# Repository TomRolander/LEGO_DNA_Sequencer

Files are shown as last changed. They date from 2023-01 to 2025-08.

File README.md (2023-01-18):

# LEGO DNA Sequencer and DIY Construction

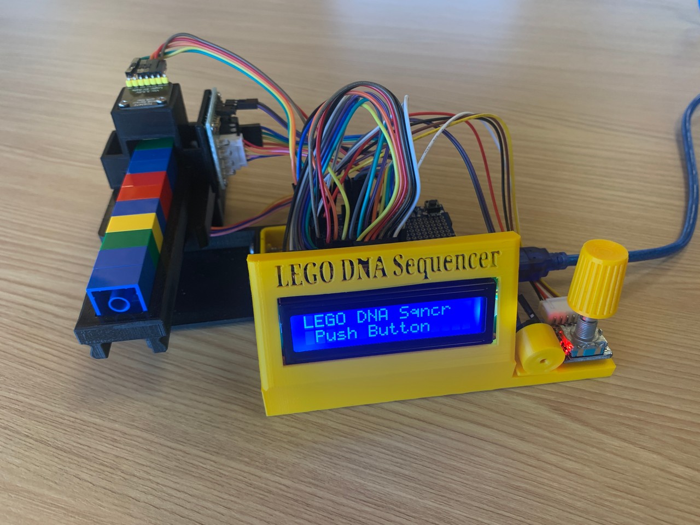
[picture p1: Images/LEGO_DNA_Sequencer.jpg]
LEGO DNA Sequencer


# Table of Contents
  
&emsp;[Overview](#overview)  
&emsp;[Documentation](#documentation)  
&emsp;&emsp;[LEGO DNA Sequencer and DIY Construction](Documentation/LEGO%20DNA%20Sequencer%20and%20DIY%20Construction.pdf)  
&emsp;&emsp;[LEGO DNA Sequencer User Manual](Documentation/LEGO%20DNA%20Sequencer%20User%20Manual.pdf)  
&emsp;[Arduino Source Code](Arduino%20Code)  
&emsp;[Arduino Breadboard](#arduino-breadboard)  
&emsp;[Arduino Schematic](#arduino-schematic)  
&emsp;[Python Remote LCD](#python-remote-lcd)  
&emsp;[STL Files for 3D Printing](STL)  

## Overview
The purpose of this LEGO DNA Sequencer and DIY Construction is to provide a complete blueprint for an open source tool that can be used to explain the complex DNA sequencing operation with a colorful easy to understand model.

All of the necessary information is provided to build your own LEGO DNA Sequencer.  The electronics assembly, 3D printed parts, software, and assembly steps are described in detail.  Also a complete Users Manual describes the operation of the LEGO DNA Sequencer.

DNA sequencing determines the order of the four chemical building blocks - called "bases" - that make up the DNA molecule.  The building blocks are composed of A (adenine), C (cytosine), G (guanine), and T (thymine).  These building blocks are represented by LEGO® 2x2 bricks of Red for G, Blue for T, Green for A, and Yellow for C. Actual DNA sequencing is greatly simplified in this model by using genomes of only 10 building blocks to identify a species.

It is beyond the scope of this document to provide more details regarding actual DNA sequencing.

[LEGO DNA Sequencer Video Demo](Images/LEGO_DNA_Sequencer%20Demo.mp4)

 ## Documentation
 The documentation for the LEGO DNA Sequencer includes a complete PDF with the DIY and also a separate extracted User Manual.

[LEGO DNA Sequencer and DIY Construction](Documentation/LEGO%20DNA%20Sequencer%20and%20DIY%20Construction.pdf)

[LEGO DNA Sequencer User Manual](Documentation/LEGO%20DNA%20Sequencer%20User%20Manual.pdf)

## Arduino Breadboard

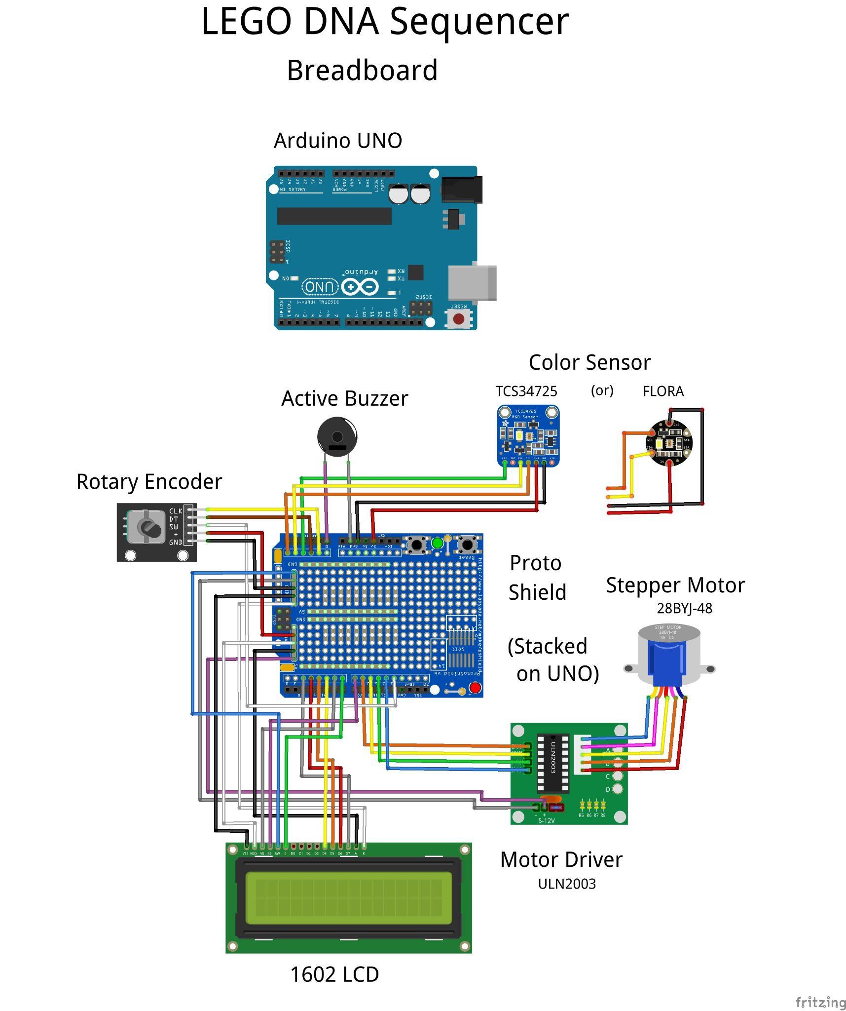
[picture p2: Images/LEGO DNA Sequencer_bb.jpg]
Arduino Breadboard


## Arduino Schematic

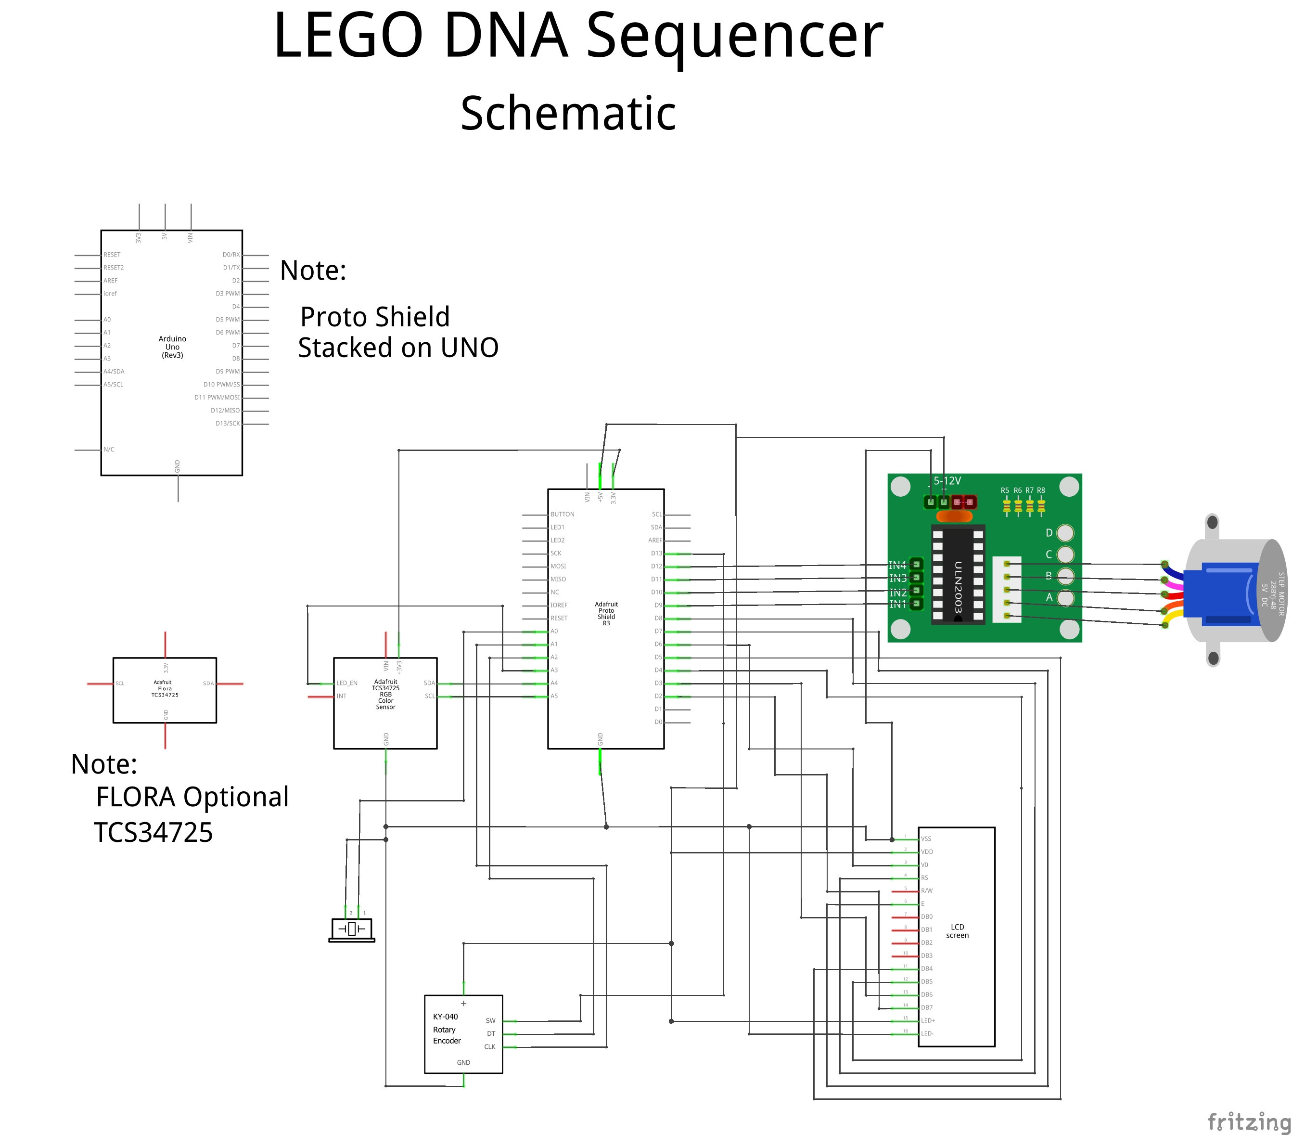
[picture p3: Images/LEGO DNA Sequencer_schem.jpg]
Arduino Schematic


## Python Remote LCD

In a classroom setting for demonstrations with the LEGO DNA Sequencer this Python code will emulate the Arduino LCD on a large screen.

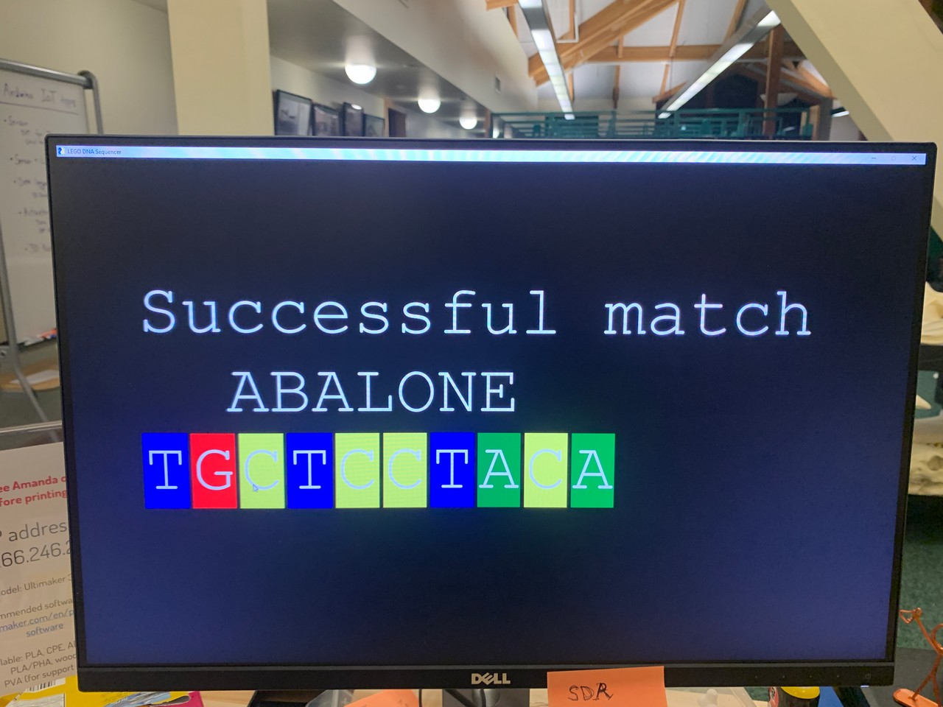
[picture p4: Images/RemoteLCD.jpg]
Remote LCD


[RemoteLCD PySimpleGUI Version](Python%20Remote%20LCD/RemoteLCD_PySimpleGUI.py)

[RemoteLCD tkinter Version](Python%20Remote%20LCD/RemoteLCD_tkinter.py)

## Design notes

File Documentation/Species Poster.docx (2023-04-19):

LEGO DNA Sequencer

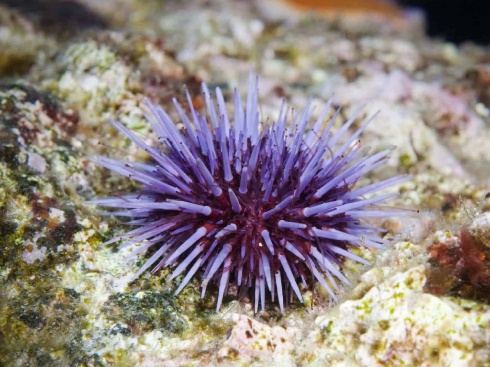
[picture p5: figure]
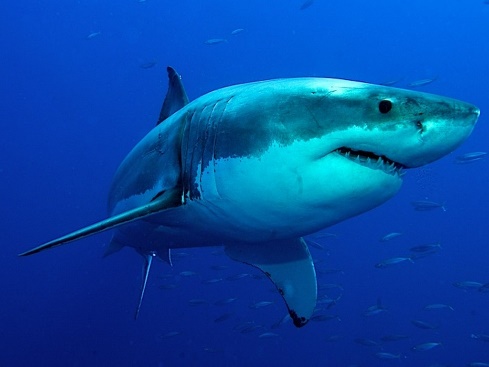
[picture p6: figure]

Sea Urchin | White Shark
CGATGACTAG | TACGCTAGCT

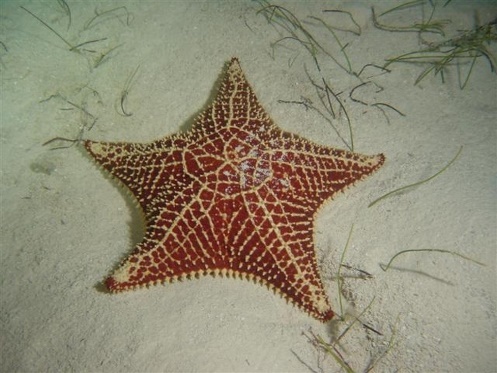
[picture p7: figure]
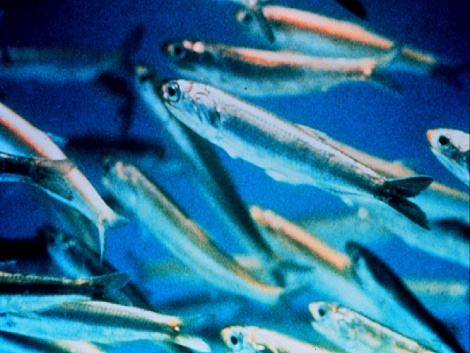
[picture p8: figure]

Sea Star | Anchovy
GATCCGATGC | ACTGATCGAT

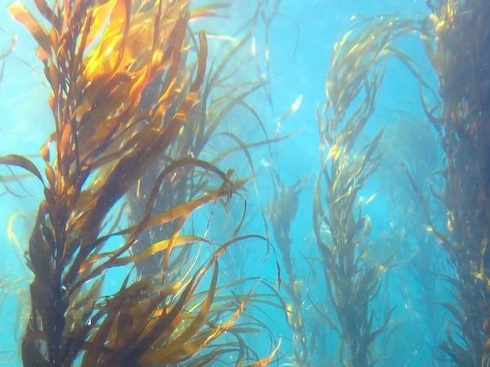
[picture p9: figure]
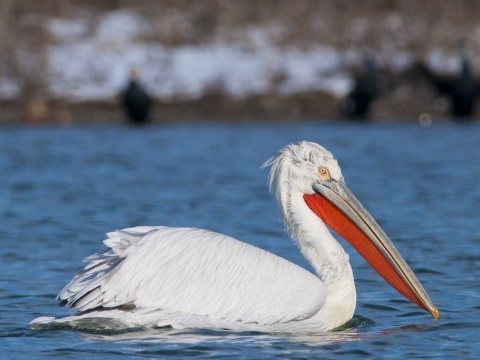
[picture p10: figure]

Giant Kelp | Pelican
TAGCTAGCTA | CAGTACGATC

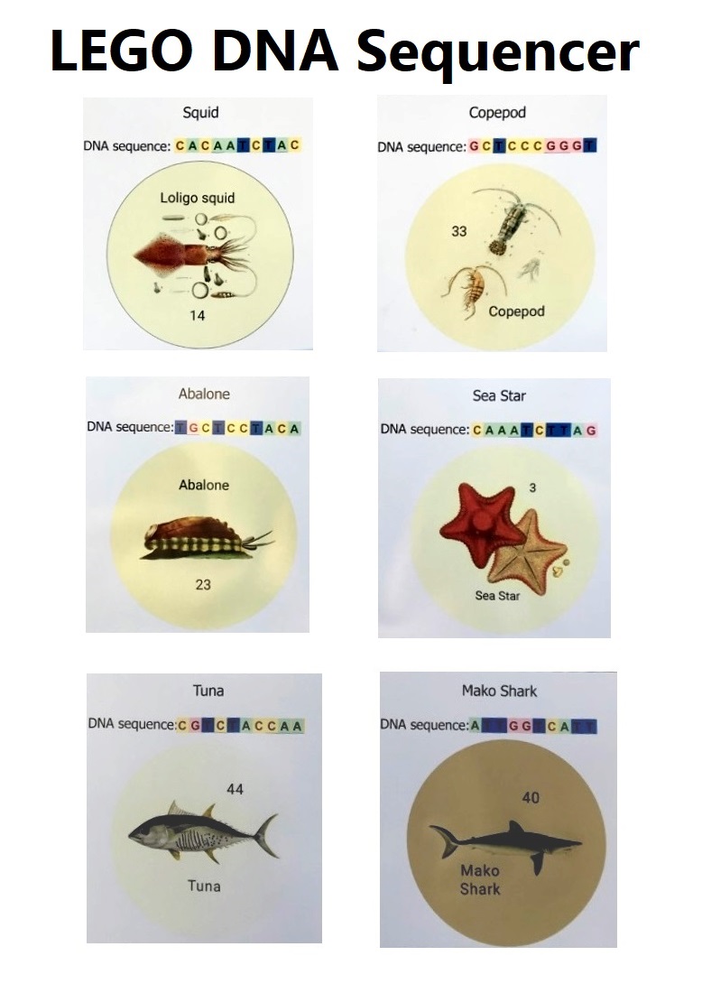
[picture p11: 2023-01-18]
Images/Poster.jpg

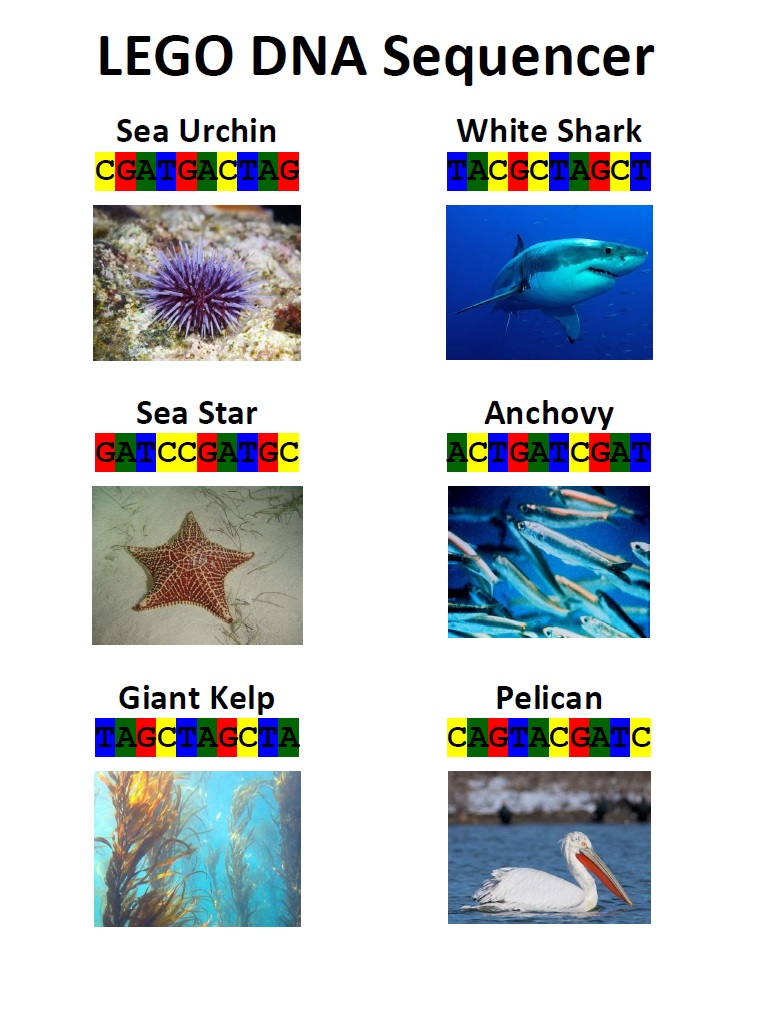
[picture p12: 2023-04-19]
Documentation/Species Poster.jpg

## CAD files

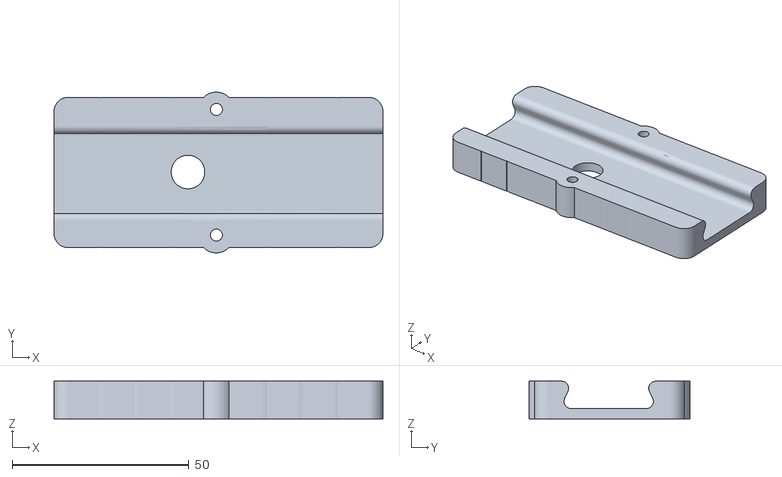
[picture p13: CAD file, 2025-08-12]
STL/LEGO DNA Sequencer - Tray Holder and Gear Mount.stl
93.0 x 45.5 x 10.7

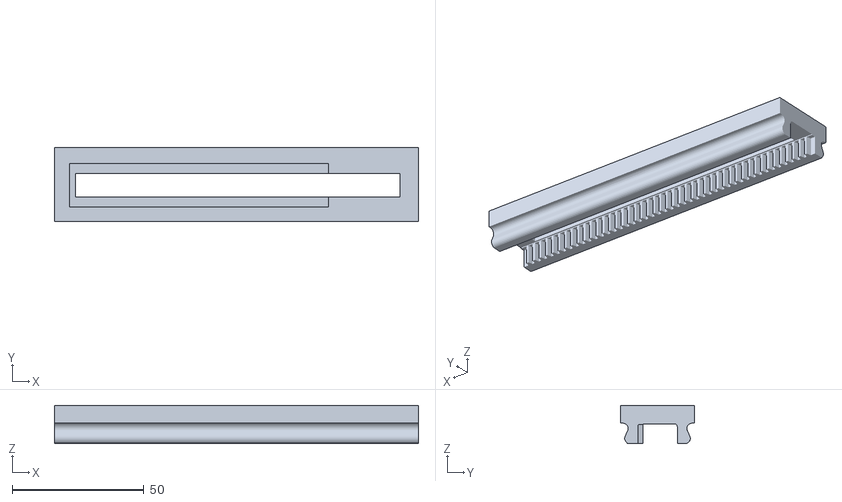
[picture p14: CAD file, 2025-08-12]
STL/LEGO DNA Sequencer - LEGO Tray.stl
138.1 x 28.0 x 14.5

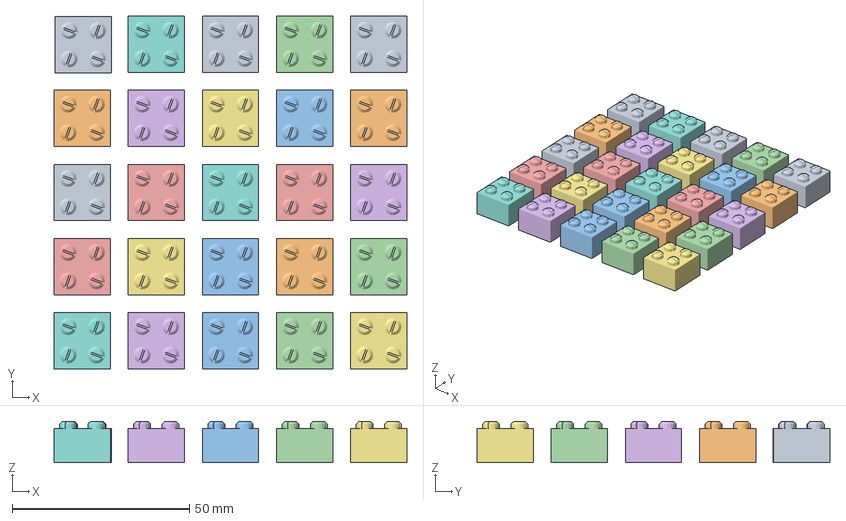
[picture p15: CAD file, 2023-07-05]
STL/LEGO Blocks x25.3mf
99.5 x 99.5 x 11.6 mm
LEGO Blocks.stl x 25

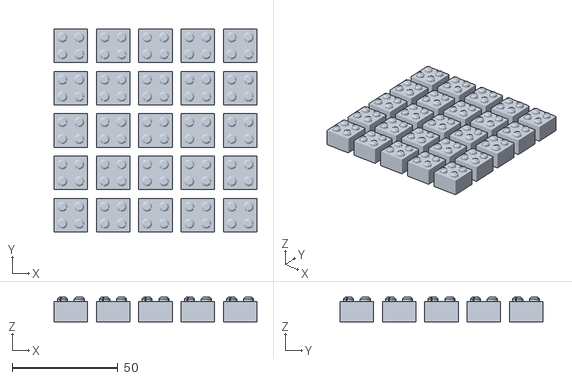
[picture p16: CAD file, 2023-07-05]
STL/LEGO DNA Sequencer - Blocks x 25.stl
95.9 x 95.9 x 11.6

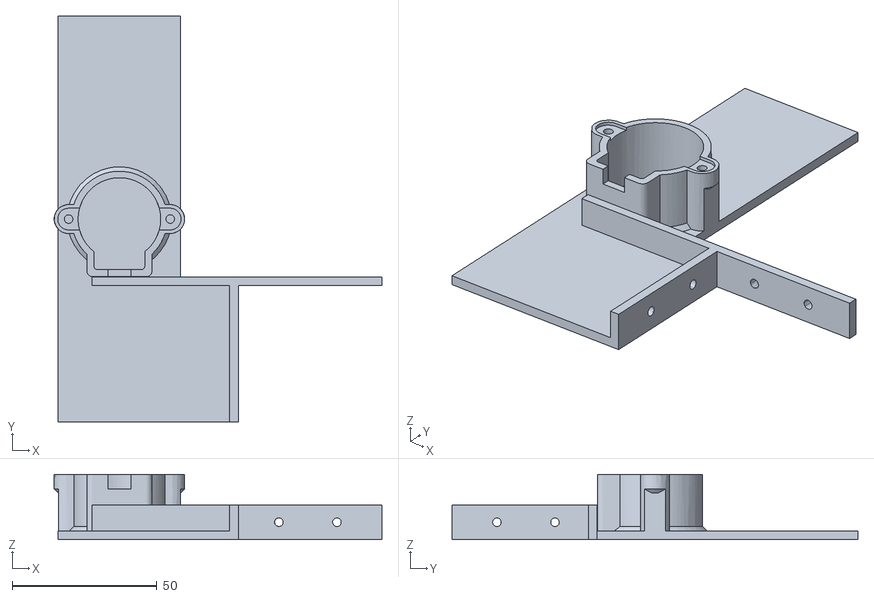
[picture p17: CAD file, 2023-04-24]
STL/LEGO DNA Sequencer - Stepper Motor Mount.stl
113.0 x 140.0 x 22.5

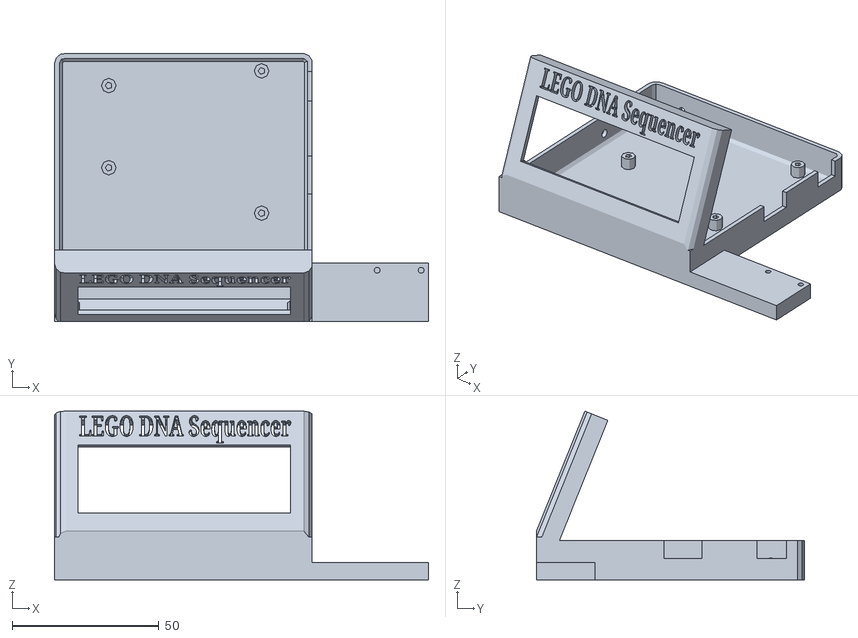
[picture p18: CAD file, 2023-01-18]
STL/LEGO DNA Sequencer - Arduino and LCD.stl
127.5 x 91.4 x 57.5

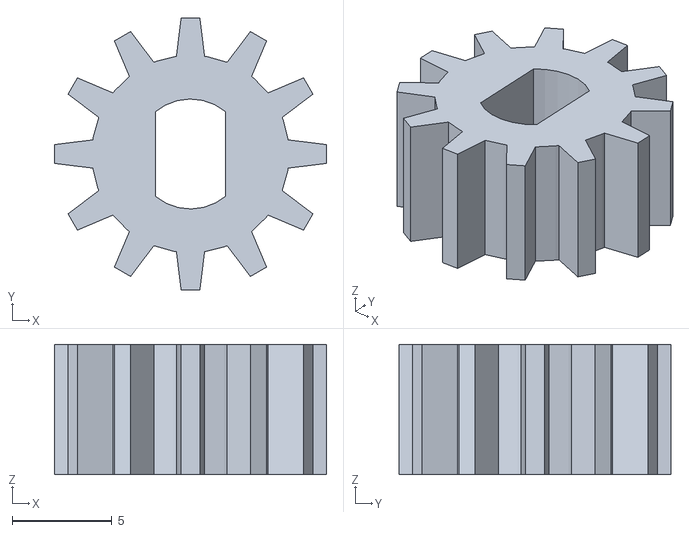
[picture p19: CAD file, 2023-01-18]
STL/LEGO DNA Sequencer - Gear.stl
13.6 x 13.6 x 6.50

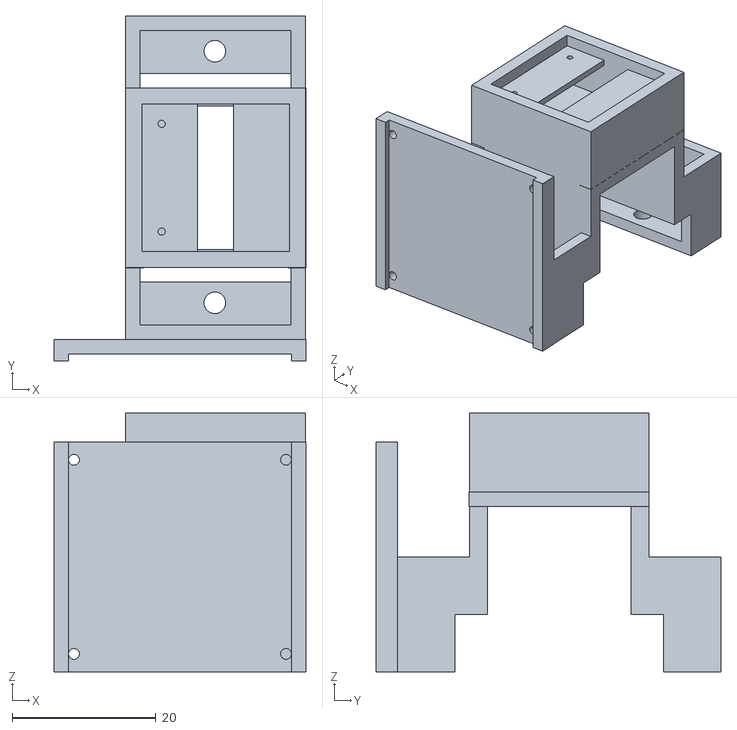
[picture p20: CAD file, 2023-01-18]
STL/LEGO DNA Sequencer - Color Sensor and Motor Drive Mount.stl
35.0 x 48.0 x 36.0

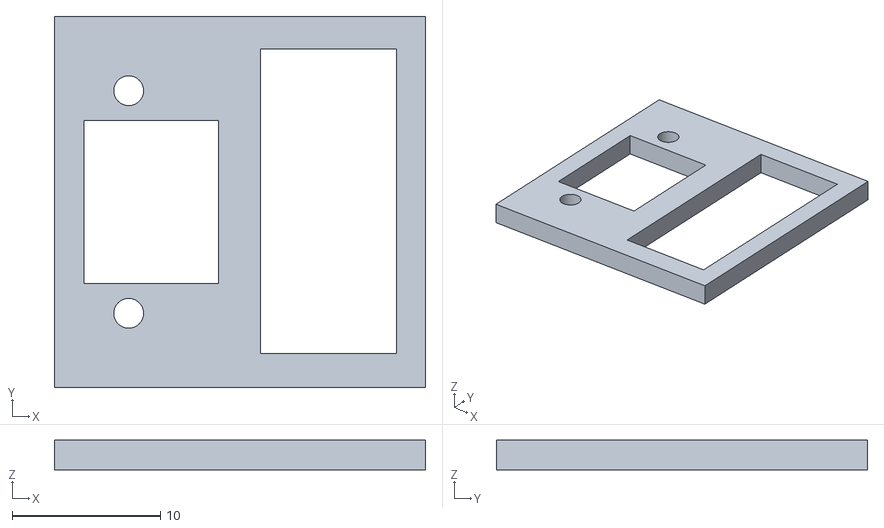
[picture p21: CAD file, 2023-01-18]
STL/LEGO DNA Sequencer - FLORA Holder.stl
25.0 x 25.0 x 2.00

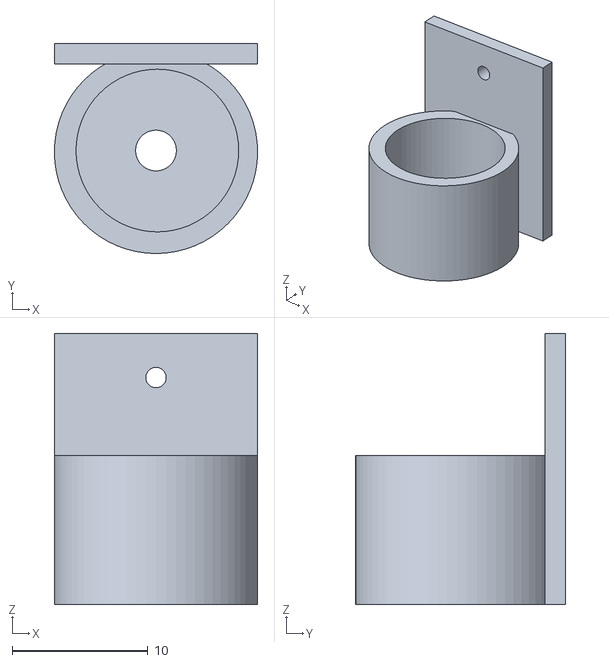
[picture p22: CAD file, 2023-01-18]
STL/LEGO DNA Sequencer - Buzzer Mount.stl
15.0 x 15.5 x 20.0

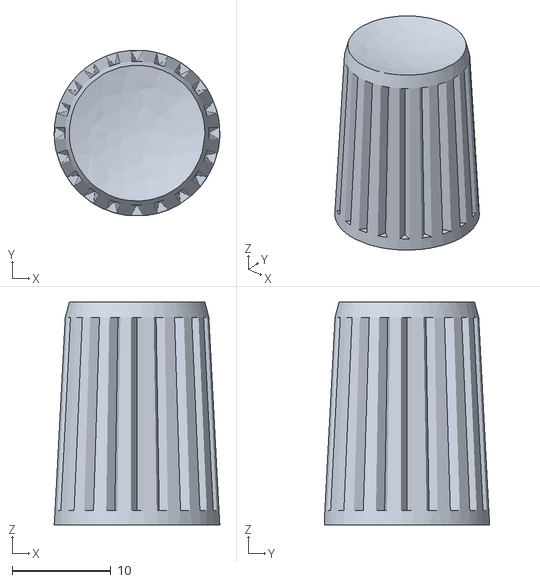
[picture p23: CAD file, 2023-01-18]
STL/LEGO DNA Sequencer - Rotary Encoder Knob.stl
16.8 x 16.7 x 22.6

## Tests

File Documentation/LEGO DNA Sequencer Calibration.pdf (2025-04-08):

# LEGO DNA Sequencer

# Calibration Steps

2024-09-25 Rev 0.1

1. Assemble the LEGOs for the CALIBRATION TEST GENOME

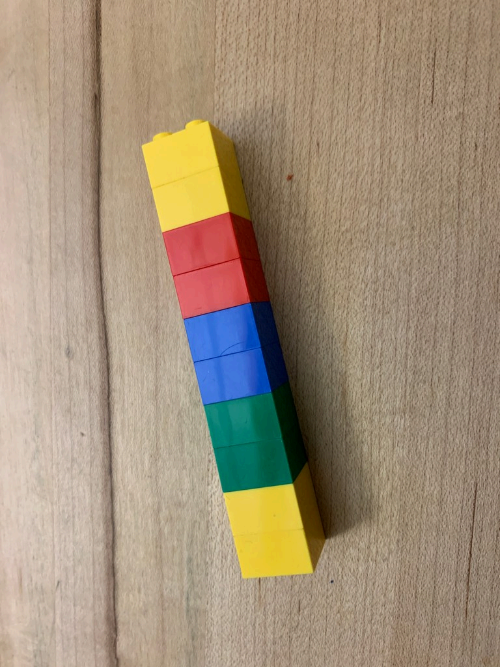
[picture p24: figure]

2. DNA Sequence the CALIBRATION TEST GENOME

Sequencing this known order of bricks will enable the system to adjust the channel threshold levels used to identify the Red, Green, Blue, and Yellow colors detected by the color sensor.

Calibration is OK if you see:
Successful Match
YYRRBBGGYY TEST

Calibration FAILED if you see: DNA not a match
UNKNOWN DNA!
Continue to step #3

3. After sequencing, and failing to recognize the CALIBRATION TEST GENOME, you will need to go to:
a. Select ADVANCED operation
b. Select AUTO CHANNEL
c. Confirm that you have just DNA Sequenced the CALIBRATION TEST GENOME
d. It will then display the current channel threshold values for CLEAR, RED, and BLUE
e. Press the button to continue
f. After clicking the button It will show the new recommended values
g. Select YES to confirm the new values or NO to continue without changing the channel settings
LEGO DNA Sequencer Calibration | - 2 -

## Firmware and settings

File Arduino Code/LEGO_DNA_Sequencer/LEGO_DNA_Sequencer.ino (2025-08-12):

/**************************************************************************
  LEGO DNA Sequencer
  Main Program

  Original Code:  2022-12-24

  Tom Rolander, MSEE
  Mentor for Circuit Design, Software, 3D Printing
  Miller Library, Fabrication Lab
  Hopkins Marine Station, Stanford University,
  120 Ocean View Blvd, Pacific Grove, CA 93950
  +1 831.915.9526 | rolander@stanford.edu

 **************************************************************************/

#define PROGRAM F("LEGO DNA Sequencer - Main Program")
#define VERSION F("Ver 0.9 2024-09-09")
#define PROGRAM_SHORT F("LEGO DNA Sqncr  ")
#define VERSION_SHORT F("Ver 0.9 09-09-24")

#define DEBUG_OUTPUT 1
#define DEBUG_MODE   0

#define FILTER_BAD_WORDS  0

#define FLORA 1

#define STATE_START       0
#define STATE_LOAD_TRAY   1
#define STATE_SEQUENCING  2

// Proc to reset the Arduino
void (* re_set)(void) = 0x00;

static bool bRemoteLCDSerial = true;

static int iState = STATE_START;

static int iStepPosition = 0;

static bool bAutomated = true;

#define BUZZER        A0

#define LED_TCS34725  A3

#if DEBUG_MODE
static bool bCommandLineMode = false;
#endif

// Rotary Encoder Inputs
#define CLK A1
#define DT A2
#define SW 13

static int iRotaryEncoder_Counter = 0;
static int iRotaryEncoder_CurrentStateCLK;
static int iRotaryEncoder_LastStateCLK;
static bool bRotaryEncoder_CurrentDirectionClockwise;
static unsigned long lastButtonPress = 0;

char sNameChars[40] = "ABCDEFGHIJKLMNOPQRSTUVWXYZ0123456789 <*";
//                     0123456789012345678901234567890123456789
//                     0         1         2         3
#define NMB_NAME_CHARS  39

char sNumberChars[13] = "0123456789<*";
//                       0123456789012
//                       0         1
#define NMB_NUMBER_CHARS  12


#if FILTER_BAD_WORDS
#include <MD5.h>
#define NMB_BAD_WORDS 10
const unsigned char ucBadWords[NMB_BAD_WORDS][16] =
{
  {0x84, 0xb9, 0x06, 0x03, 0x0d, 0x48, 0x52, 0x7c, 0xe0, 0x5c, 0x36, 0x82, 0x0f, 0x94, 0xc9, 0xa3},
  {0x01, 0x2e, 0x3b, 0x42, 0x29, 0xed, 0x77, 0x78, 0x85, 0x07, 0x44, 0xbb, 0x32, 0x7f, 0xa5, 0x54},
  {0x71, 0xb4, 0x74, 0xfa, 0x0a, 0x68, 0x85, 0x32, 0x55, 0x2a, 0x0a, 0x95, 0x46, 0x4a, 0x9a, 0x00},
  {0x4f, 0x79, 0x1f, 0x1f, 0xc2, 0xf1, 0xbc, 0x1a, 0x86, 0xab, 0xc3, 0x8d, 0x46, 0x78, 0x9b, 0x34},
  {0x00, 0x94, 0xcf, 0x00, 0x63, 0x7a, 0xee, 0x49, 0xb2, 0x3c, 0x4f, 0x44, 0xba, 0xaf, 0xe0, 0xde},
  {0x4a, 0x46, 0x6a, 0x30, 0x2e, 0x55, 0xdd, 0x2e, 0x4e, 0x8d, 0xf6, 0xde, 0xa7, 0xaa, 0xc3, 0x2f},
  {0xbe, 0x97, 0x62, 0x73, 0xca, 0x31, 0x79, 0xad, 0x77, 0x72, 0x63, 0xfb, 0x26, 0xac, 0x08, 0xd4},
  {0x27, 0x50, 0xfe, 0xdb, 0xda, 0x13, 0x41, 0xe9, 0x84, 0x2b, 0xdd, 0xb7, 0x44, 0xc8, 0x62, 0x03},
  {0xa0, 0x15, 0x4f, 0x58, 0xd6, 0xa4, 0x46, 0x1c, 0x9d, 0x35, 0x3d, 0x04, 0xd6, 0x3d, 0xb0, 0x8b},
  {0xf7, 0x3e, 0x87, 0x12, 0x37, 0x3e, 0xba, 0xab, 0xa7, 0xf8, 0xb6, 0x91, 0xa1, 0x92, 0x24, 0xeb}
};
#endif

#include <EEPROM.h>

#define EEPROM_LEGO_SIGNATURE F("LEGO");

// EEPROM state variables
#define EEPROM_SIZE 512

#define EEPROM_SIGNATURE                    0 // 000-003  Signature 'LEGO'
#define EEPROM_CLEAR_CHANNEL_THRESHHOLD     4 // 004-005  iRED_CHANNEL_THRESHHOLD
#define EEPROM_RED_CHANNEL_THRESHHOLD       6 // 006-007  iRED_CHANNEL_THRESHHOLD
#define EEPROM_BLUE_CHANNEL_THRESHHOLD      8 // 008-009  iBLUE_CHANNEL_THRESHHOLD
#define EEPROM_REMOTE_LCD_SERIAL           10 // 010-010  bRemoteLCDSerial
#define EEPROM_NUMBER_OF_LEGO_DNA          11 // 011-011  iNumberOfEEPROM
#define EEPROM_LEGO_DNA                    12 // 012-511  LEGO_DNAs

#define EEPROM_LEGO_DNA_MAX                4
#define EEPROM_LEGO_DNA_ENTRY_SIZE         28

#define LEGO_DNA_MAX  11

static int iNumberOfEEPROM = 0;

#define NMB_LEGO_BRICKS 10

int iBrickSequencing[NMB_LEGO_BRICKS][4];
char sDNASequence[NMB_LEGO_BRICKS + 1] = "";


int iLEGO_DNA_Number = 7;
#if 1
char sLEGO_DNA_Sequence[LEGO_DNA_MAX][NMB_LEGO_BRICKS + 1] =
{ "CCGGTTAACC",
  "CGATGACTAG",
  "TACGCTAGCT",
  "GATCCGATGC",
  "ACTGATCGAT",
  "TAGCTAGCTA",
  "CAGTACGATC"
};
char sLEGO_DNA_Name[LEGO_DNA_MAX][17] =
{ " YYRRBBGGYY TEST",
  "  SEA URCHIN    ",
  "  WHITE SHARK   ",
  "  SEA STAR      ",
  "  ANCHOVY       ",
  "  GIANT KELP    ",
  "  PELICAN       "
};
#endif
#if 0
char sLEGO_DNA_Sequence[LEGO_DNA_MAX][NMB_LEGO_BRICKS + 1] =
{ "CCGGTTAACC",
  "ATTGGTCATT",
  "TGCTCCTACA",
  "CACAATCTAC",
  "GCTCCCGGGT",
  "CAAATCTTAG",
  "CGTCTACCAA"
};
char sLEGO_DNA_Name[LEGO_DNA_MAX][17] =
{ " YYRRBBGGYY TEST",
  "  MAKO SHARK    ",
  "  ABALONE       ",
  "  SQUID         ",
  "  COPEPOD       ",
  "  SEA STAR      ",
  "  TUNA          "
};
#endif

#include <LiquidCrystal.h>
int Contrast = 75;
LiquidCrystal lcd(8, 7, 5, 4, 3, 2);

//Includes the Arduino Stepper Library
#include <Stepper.h>

// Defines the number of steps per rotation
const int stepsPerRevolution = 2038;

#define STEPPER_PIN_1 9
#define STEPPER_PIN_2 10
#define STEPPER_PIN_3 11
#define STEPPER_PIN_4 12

#define OFFSET_TO_FIRST_BRICK 460
#define STEPS_PER_LEGO_BRICK  550
#define STEPS_PER_AUTO_POSITION   25
#define OFFSET_AUTO_POSITION  200

// Creates an instance of stepper class
// Pins entered in sequence IN1-IN3-IN2-IN4 for proper step sequence
Stepper myStepper = Stepper(stepsPerRevolution, STEPPER_PIN_1, STEPPER_PIN_3, STEPPER_PIN_2, STEPPER_PIN_4);

#if DEBUG_MODE
#define MAINTENANCE_NMB_OPS           10
#else
#define MAINTENANCE_NMB_OPS           9
#endif
#define MAINTENANCE_OP_CANCEL         0
#if DEBUG_MODE
#define MAINTENANCE_OP_COMMAND_LINE   1
#define MAINTENANCE_OP_UNLOAD_TRAY    2
#define MAINTENANCE_OP_LOAD_TRAY      3
#define MAINTENANCE_OP_POSITION_TRAY  4
#define MAINTENANCE_OP_ZERO_NEW_DNA   5
#define MAINTENANCE_OP_BUZZER_OFF     6
#define MAINTENANCE_OP_BUZZER_ON      7
#define MAINTENANCE_OP_ADVANCED       8
#define MAINTENANCE_OP_VERSION_INFO   9
#endif
#define MAINTENANCE_OP_UNLOAD_TRAY    1
#define MAINTENANCE_OP_LOAD_TRAY      2
#define MAINTENANCE_OP_POSITION_TRAY  3
#define MAINTENANCE_OP_ZERO_NEW_DNA   4
#define MAINTENANCE_OP_BUZZER_OFF     5
#define MAINTENANCE_OP_BUZZER_ON      6
#define MAINTENANCE_OP_ADVANCED       7
#define MAINTENANCE_OP_VERSION_INFO   8

char sMaintenanceOp[MAINTENANCE_NMB_OPS][17] =
{ "  CANCEL        ",
#if DEBUG_MODE
  "  COMMAND LINE  ",
#endif
  "  UNLOAD TRAY   ",
  "  LOAD TRAY     ",
  "  POSITION TRAY ",
  "  ZERO NEW DNA  ",
  "  BUZZER OFF    ",
  "  BUZZER ON     ",
  "  ADVANCED      ",
  "  VERSION INFO  "
};

#define ADVANCED_NMB_OPS            9

#define ADVANCED_OP_CANCEL          0
#define ADVANCED_OP_CLEAR_CHANNEL   1
#define ADVANCED_OP_RED_CHANNEL     2
#define ADVANCED_OP_BLUE_CHANNEL    3
#define ADVANCED_OP_AUTO_CHANNEL    4
#define ADVANCED_OP_AUTO_POSITION   5
#define ADVANCED_OP_REMOTE_LCD_ON   6
#define ADVANCED_OP_REMOTE_LCD_OFF  7
#define ADVANCED_OP_REBOOT          8

char sAdvancedOp[ADVANCED_NMB_OPS][17] =
{ "  CANCEL        ",
  "  CLEAR CHANNEL ",
  "  RED CHANNEL   ",
  "  BLUE CHANNEL  ",
  "  AUTO CHANNEL  ",
  "  AUTO POSITION ",
  "  REMOTE LCD ON ",
  "  REMOTE LCD OFF",
  "  REBOOT        "
};


static bool bBuzzer = true;

#include <Wire.h>
#include "Adafruit_TCS34725.h"

#define CLEAR   -1
#define RED     'G'
#define GREEN   'A'
#define BLUE    'T'
#define YELLOW  'C'

/* Initialise with specific int time and gain values */
Adafruit_TCS34725 tcs = Adafruit_TCS34725(TCS34725_INTEGRATIONTIME_50MS, TCS34725_GAIN_16X);

#if FLORA
#define CLEAR_CHANNEL_THRESHHOLD  130
#define RED_CHANNEL_THRESHHOLD  35
#define BLUE_CHANNEL_THRESHHOLD  30
#else
#define CLEAR_CHANNEL_THRESHHOLD  900
#define RED_CHANNEL_THRESHHOLD  170
#define BLUE_CHANNEL_THRESHHOLD  220
#endif

static int iCLEAR_CHANNEL_THRESHHOLD = CLEAR_CHANNEL_THRESHHOLD;
static int iRED_CHANNEL_THRESHHOLD = RED_CHANNEL_THRESHHOLD;
static int iBLUE_CHANNEL_THRESHHOLD = BLUE_CHANNEL_THRESHHOLD;

void setup() {
  Serial.begin(115200);
  delay(1000);
  
#if DEBUG_OUTPUT
  Serial.println();
  Serial.println(PROGRAM);
  Serial.println(VERSION);
#endif

  pinMode(BUZZER, OUTPUT); //initialize the buzzer pin as an output

  // Set encoder pins as inputs
  pinMode(CLK, INPUT);
  pinMode(DT, INPUT);
  pinMode(SW, INPUT_PULLUP);

  // Read the initial state of CLK
  iRotaryEncoder_LastStateCLK = digitalRead(CLK);

  analogWrite(6, Contrast);
  lcd.begin(16, 2);

  pinMode (LED_TCS34725, OUTPUT);
  digitalWrite (LED_TCS34725, LOW);

  if (tcs.begin()) {
#if DEBUG_OUTPUT
    Serial.println(F("Found sensor"));
#endif    
    // LED off to prevent overheating
    tcs.setInterrupt(true);

  } else {
    Serial.println(F("No TCS34725 found ... check your connections"));
    while (1);
  }

  myStepper.setSpeed(10);

  char cBuffer[5];
  int nChars;
  long lStartTime = millis();

#if DEBUG_MODE
  bCommandLineMode = true;
  lcd.setCursor(0, 0);
  lcd.print(F("LEGO DNA Sqncr  "));
  lcd.setCursor(0, 1);
  lcd.print(F("Debugger Console"));
#else
  StartSequencer();
#endif

#if DEBUG_OUTPUT
  for (int i = 0; i < 128; i++)
  {
    int iByte = EEPROM[i];
    if (i % 16 == 0)
      Serial.println("");
    if (iByte < 16)
      Serial.print(F("0"));
    Serial.print(iByte, HEX);
    Serial.print(F(" "));
  }
  Serial.println("");
#endif

  LoadEEPROM();
  
  Beeps(3, 10, 200);  // 3 Beeps, 10MS ON, 200MS OFF
}

void LoadEEPROM()
{
  if (EEPROM[EEPROM_SIGNATURE + 0] == 'L' &&
      EEPROM[EEPROM_SIGNATURE + 1] == 'E' &&
      EEPROM[EEPROM_SIGNATURE + 2] == 'G' &&
      EEPROM[EEPROM_SIGNATURE + 3] == 'O')
  {
    iCLEAR_CHANNEL_THRESHHOLD = readUnsignedIntFromEEPROM(EEPROM_CLEAR_CHANNEL_THRESHHOLD);
    iRED_CHANNEL_THRESHHOLD = readUnsignedIntFromEEPROM(EEPROM_RED_CHANNEL_THRESHHOLD);
    iBLUE_CHANNEL_THRESHHOLD = readUnsignedIntFromEEPROM(EEPROM_BLUE_CHANNEL_THRESHHOLD);
    bRemoteLCDSerial= EEPROM[EEPROM_REMOTE_LCD_SERIAL];
    iNumberOfEEPROM = EEPROM[EEPROM_NUMBER_OF_LEGO_DNA];

    int index;
    int iOffset = EEPROM_LEGO_DNA;
    for (index = 0; index < iNumberOfEEPROM; index++)
    {
      for (int i = 0; i < 11; i++)
      {
        sLEGO_DNA_Sequence[iLEGO_DNA_Number][i] = EEPROM[iOffset];
        iOffset = iOffset + 1;
      }
      for (int i = 0; i < 17; i++)
      {
        sLEGO_DNA_Name[iLEGO_DNA_Number][i] = EEPROM[iOffset];
        iOffset = iOffset + 1;
      }
#if DEBUG_OUTPUT
      Serial.println(F("EEPROM Data"));
      Serial.print(F("Index "));
      Serial.print(iLEGO_DNA_Number);
      Serial.print(F(" ["));
      Serial.print(&sLEGO_DNA_Sequence[iLEGO_DNA_Number][0]);
      Serial.print(F("] ["));
      Serial.print(&sLEGO_DNA_Name[iLEGO_DNA_Number][0]);
      Serial.println(F("]"));
#endif
      iLEGO_DNA_Number = iLEGO_DNA_Number + 1;
    }
  }
  else
  {
#if DEBUG_OUTPUT
    Serial.println(F("EEPROM LEGO not found"));
#endif
    SetupEEPROM();
  }
#if DEBUG_OUTPUT
  Serial.println(F("EEPROM LEGO found"));
  Serial.print(F("bRemoteLCDSerial = "));
  Serial.println(bRemoteLCDSerial);
  Serial.print(F("iNumberOfEEPROM = "));
  Serial.println(iNumberOfEEPROM);
  Serial.print(F("Clear Channel Threshhold = "));
  Serial.println(iCLEAR_CHANNEL_THRESHHOLD);
  Serial.print(F("Red   Channel Threshhold = "));
  Serial.println(iRED_CHANNEL_THRESHHOLD);
  Serial.print(F("Blue  Channel Threshhold = "));
  Serial.println(iBLUE_CHANNEL_THRESHHOLD);
#endif  
}

void writeUnsignedIntIntoEEPROM(int address, unsigned int number)
{
  EEPROM[address] = number >> 8;
  EEPROM[address + 1] = number & 0xFF;
}

unsigned int readUnsignedIntFromEEPROM(int address)
{
  return (EEPROM[address] << 8) + EEPROM[address + 1];
}

void SetupEEPROM()
{
  EEPROM[EEPROM_SIGNATURE + 0] = 'L';
  EEPROM[EEPROM_SIGNATURE + 1] = 'E';
  EEPROM[EEPROM_SIGNATURE + 2] = 'G';
  EEPROM[EEPROM_SIGNATURE + 3] = 'O';
  writeUnsignedIntIntoEEPROM(EEPROM_CLEAR_CHANNEL_THRESHHOLD, iCLEAR_CHANNEL_THRESHHOLD);
  writeUnsignedIntIntoEEPROM(EEPROM_RED_CHANNEL_THRESHHOLD, iRED_CHANNEL_THRESHHOLD);
  writeUnsignedIntIntoEEPROM(EEPROM_BLUE_CHANNEL_THRESHHOLD, iBLUE_CHANNEL_THRESHHOLD);
  EEPROM[EEPROM_REMOTE_LCD_SERIAL] = bRemoteLCDSerial;
  EEPROM[EEPROM_NUMBER_OF_LEGO_DNA] = iNumberOfEEPROM;
  

#if DEBUG_OUTPUT
  Serial.println(F("EEPROM LEGO initialized"));
#endif

}
void UpdateLCD(char cColor, int index)
{
  char lcd1[17] = "Sequencing DNA  ";
  char lcd2[17] = "                ";
  lcd2[index] = cColor;
  for(int i=0; i<index; i++)
    lcd2[i] = sDNASequence[i];
  RemoteLCDSerial(lcd1, lcd2);
  lcd.print(cColor);
}

void print4digits(uint16_t iVal)
{
  if (iVal < 10) {
    Serial.print(F("   ")); // 3 spaces
  } else if (iVal < 100) {
    Serial.print(F("  ")); // 2 spaces
  } else if (iVal < 1000) {
    Serial.print(F(" ")); // 1 space
  } 
  Serial.print(iVal);
}

char GetLEGOColor(int index)
{
  char cRetcode = '\0';

  uint16_t r, g, b, c;

  tcs.getRawData(&r, &g, &b, &c);

  iBrickSequencing[index][0] = r;
  iBrickSequencing[index][1] = g;
  iBrickSequencing[index][2] = b;
  iBrickSequencing[index][3] = c;
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
void loop()
{
#if DEBUG_MODE
  if (bCommandLineMode)
  {
    if (Serial.available() > 0)
    {
      char cBuffer[7];
      int nChars;
      int iValue = 0;

      nChars = Serial.readBytes(cBuffer, sizeof(cBuffer));
      Serial.print(F("nChars = "));
      Serial.println(nChars);
      cBuffer[nChars] = '\0';
      Serial.print(F("cBuffer = "));
      Serial.println(cBuffer);

      cBuffer[0] = toupper(cBuffer[0]);

      if (nChars == 1)
      {
        switch (cBuffer[0])
        {
          case 'Z':
            iNumberOfEEPROM = 0;
            iLEGO_DNA_Number = 6;
            for (int i = 0; i < 512; i++)
              EEPROM[i] = '\0';
            SetupEEPROM();
            break;

          case 'E':
            StartSequencer();
            iState = STATE_START;
            bCommandLineMode = false;
            return;

          case 'M':
            bAutomated = false;
            break;

          case 'A':
            bAutomated = true;
            break;

          case 'C':
            GetLEGOColor(0);
            break;

          case 'K':
            while (Serial.available() <= 0)
            {
              GetLEGOColor(0);
              delay(500);
            }
            nChars = Serial.readBytes(cBuffer, sizeof(cBuffer));
            help();
            break;

          case '1':
            tcs.setInterrupt(false);
            digitalWrite (LED_TCS34725, HIGH);
            break;

          case '0':
            tcs.setInterrupt(true);
            digitalWrite (LED_TCS34725, LOW);
            break;

          default:
            Serial.println(F("Unrecognized command!"));
            help();
            break;
        }
        return;
      }
      if (nChars != 5 ||
          (cBuffer[0] != 'L' && cBuffer[0] != 'R' && cBuffer[0] != 'S'))
      {
        help();
        return;
      }

      for (int i = 1; i < 5; i++)
      {
        iValue = (iValue * 10) + (cBuffer[i] - '0');
      }
      Serial.print(F("Value = "));
      if (cBuffer[0] == 'R')
        iValue = 0 - iValue;
      Serial.println(iValue);

      if (cBuffer[0] == 'S')
        myStepper.setSpeed(iValue);
      else
      {
        MoveTray(iValue);
        GetLEGOColor(0);
      }
    }
    return;
  }
#endif

  if (iState == STATE_START)
  {
    if (GetButtonPressed())
    {
      //      while (digitalRead(SW) == LOW)
      //        ;
      iState = STATE_LOAD_TRAY;
    }
    else
    {
      return;
    }
  }

  if (iState == STATE_LOAD_TRAY)
  {
    F_RemoteLCDSerial(F("Load LEGO Tray  "), F(" Push Button    ")); 
    lcd.setCursor(0, 0);
    lcd.print(F("Load LEGO Tray  "));
    lcd.setCursor(0, 1);
    lcd.print(F(" Push Button    "));

    Beeps(1, 5, 0);  // 1 Beep, 5MS ON, 0MS OFF

    while (GetButtonPressed() == false)
    {
      if (CheckRotaryEncoder())
      {
        lcd.setCursor(0, 0);
        lcd.print(F("Select Option:  "));

        int iMaintenanceOp = MAINTENANCE_OP_CANCEL;

        while (true)
        {
          lcd.setCursor(0, 1);
          lcd.print(sMaintenanceOp[iMaintenanceOp]);

          if (GetButtonPressed())
            break;

          int iCounter = iRotaryEncoder_Counter;
          if (CheckRotaryEncoder())
          {
            if (iRotaryEncoder_Counter > iCounter)
            {
              iMaintenanceOp++;
              if (iMaintenanceOp  >= MAINTENANCE_NMB_OPS)
                iMaintenanceOp = MAINTENANCE_OP_CANCEL;
            }
            else
            {
              iMaintenanceOp--;
              if (iMaintenanceOp < 0)
                iMaintenanceOp = MAINTENANCE_OP_VERSION_INFO;
            }
          }
        }

        switch (iMaintenanceOp)
        {
          case MAINTENANCE_OP_CANCEL:
#if DEBUG_OUTPUT
            Serial.println(F("Cancel"));
#endif            
            StartSequencer();
            iState = STATE_START;
#if DEBUG_MODE
            bCommandLineMode = false;
#endif
            break;

#if DEBUG_MODE
          case MAINTENANCE_OP_COMMAND_LINE:
            Serial.println(F("Enter Command Line Mode"));
            bCommandLineMode = true;
            break;
#endif

          case MAINTENANCE_OP_UNLOAD_TRAY:
#if DEBUG_OUTPUT
            Serial.println(F("Unload Tray"));
#endif            
            myStepper.step(-4000);
            iStepPosition = 0;
            break;

          case MAINTENANCE_OP_LOAD_TRAY:
#if DEBUG_OUTPUT
            Serial.println(F("Load Tray"));
#endif            
            myStepper.step(1640);
            iStepPosition = 0;
            break;

          case MAINTENANCE_OP_POSITION_TRAY:
#if DEBUG_OUTPUT
            Serial.println(F("Position Tray"));
#endif            
            {
              int iCounter = iRotaryEncoder_Counter;
              while (GetButtonPressed() == false)
              {
                if (CheckRotaryEncoder())
                {
#if DEBUG_OUTPUT
#if 0
                  Serial.print(F("iCounter = "));
                  Serial.print(iCounter);
                  Serial.print(F("  iRotaryEncoder_Counter = "));
                  Serial.println(iRotaryEncoder_Counter);
#endif
#endif
                  if (iRotaryEncoder_Counter > iCounter)
                    MoveTray(50);
                  else
                    MoveTray(-50);
                  iCounter = iRotaryEncoder_Counter;
                }
              }
            }
            break;

          case MAINTENANCE_OP_ZERO_NEW_DNA:
            iNumberOfEEPROM = 0;
            iLEGO_DNA_Number = 6;
            for (int i = EEPROM_NUMBER_OF_LEGO_DNA; i < 512; i++)
              EEPROM[i] = '\0';
            SetupEEPROM();
            break;

          case MAINTENANCE_OP_BUZZER_ON:
            bBuzzer = true;
            break;

          case MAINTENANCE_OP_BUZZER_OFF:
            bBuzzer = false;
            break;

          case MAINTENANCE_OP_ADVANCED:
            Advanced();
            break;

          case MAINTENANCE_OP_VERSION_INFO:
            lcd.setCursor(0, 0);
            lcd.print(PROGRAM_SHORT);
            lcd.setCursor(0, 1);
            lcd.print(VERSION_SHORT);
            while (GetButtonPressed() == false &&
                   CheckRotaryEncoder() == false)
            {
              delay(100);
            }
            break;
        }

        return;
      }
    }
    iState = STATE_SEQUENCING;
  }

  lcd.setCursor(0, 0);
  lcd.print(F("Sequencing DNA  "));
  lcd.setCursor(0, 1);
  lcd.print(F("                "));

  F_RemoteLCDSerial(F("Sequencing DNA  "),F("                "));

  lcd.setCursor(0, 1);


  // STATE_SEQUENCING
  tcs.setInterrupt(false);
  digitalWrite (LED_TCS34725, HIGH);

  myStepper.setSpeed(10);
  iStepPosition = 0;
  MoveTray(OFFSET_TO_FIRST_BRICK);

  sDNASequence[NMB_LEGO_BRICKS] = '\0';

#if DEBUG_OUTPUT
  Serial.println("");
  Serial.println(F("---------- CSV ----------"));
  Serial.println(F("   P,   R,   G,   B,   Y, M,DNA"));
#endif

  for (int i = 0; i < NMB_LEGO_BRICKS; i++)
  {
    if (bAutomated == false)
    {
      lcd.setCursor(0, 0);
      lcd.print(F("Position LEGO # "));
      lcd.print(i);
      lcd.setCursor(0, 1);
      lcd.print(F(" Push Button    "));

      while (GetButtonPressed() == false)
        ;
    }

    delay(100); // Delay a little for visual effect
    sDNASequence[i] = GetLEGOColor(i);

    if (i < 9)
    {
      Beeps(1, 2, 0);   // 1 Beep, 2MS ON, 0MS OFF
      MoveTray(STEPS_PER_LEGO_BRICK);
    }
    else
    {
      tcs.setInterrupt(true);
      digitalWrite (LED_TCS34725, LOW);

      lcd.setCursor(0, 0);
      lcd.print(F("Unloading tray  "));

      char lcd1[17] = "Unloading tray  ";
      char lcd2[17] = "                ";
      for(int i=0; i<NMB_LEGO_BRICKS; i++)
        lcd2[i] = sDNASequence[i];
      RemoteLCDSerial(lcd1, lcd2);       

      Beeps(2, 5, 250);  // 2 Beeps, 5MS ON, 250MS OFF

      myStepper.setSpeed(15);
      MoveTray(-5410);

#if DEBUG_MODE
      Serial.print(F("["));
      Serial.print(sDNASequence);
      Serial.println(F("]"));
      for (int i = 0; i < NMB_LEGO_BRICKS; i++)
      {
        for (int j = 0; j < 4; j++)
        {
          Serial.print(iBrickSequencing[i][j]);
          Serial.print(F(" "));
        }
        Serial.println("");
      }
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

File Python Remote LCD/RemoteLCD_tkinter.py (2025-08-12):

"""
/**************************************************************************
  RemoteLDC_tkinter
    The purpose of this Python program is to remotely display the
  contents of an Arduino 1602 LCD.  It was created to facilitate 
  a large group of persons watching the LEGO DNA Sequencer.

  Original Code:  2023-01-08
  Revision:       2022-01-10

  Tom Rolander, MSEE
  Mentor, Circuit Design & Software
  Miller Library, Fabrication Lab
  Hopkins Marine Station, Stanford University,
  120 Ocean View Blvd, Pacific Grove, CA 93950
  +1 831.915.9526 | rolander@stanford.edu

 **************************************************************************/

"""
Program = "RemoteLCD_tkinter"
Version = "Ver 0.1"
RevisionDate = "2023-01-10"

import sys
import os
import tkinter as tk
import time
import serial
import argparse
from types import NoneType


def Draw():
    global text
    frame=tk.Frame(root,bd=1)
    frame.place(x=10,y=10)
    frame.pack(side="left")
    text=tk.Label(frame,text='', font=("Courier", 120))
    text.pack()
    text.configure(text= "  Welcome\n  LEGO DNA Sqncr")

def Refresher():
    global text
    if SerialObj.in_waiting != 0:
        letter = SerialObj.read()
        if letter == b'[':
            lcd1 = SerialObj.read(16)
            SerialObj.read(2)   #Ignore the '\r\n'
            lcd2 = SerialObj.read(16)
            SerialObj.read(1)   #Ignore the ']'
            #text.configure(text="0123456789012345\n" + time.asctime())
            text.configure(text= "  " + str(lcd1, 'UTF-8') + "\n  " + str(lcd2, 'UTF-8'))
            #text.configure(text= lcd1 + "\n" + lcd2)
    root.after(10, Refresher) 

print (Program, Version, RevisionDate)

parser = argparse.ArgumentParser("RemoteLCD")
parser.add_argument('--comport', type=str, required=False, help="COM port")
parser.add_argument('--showports', required=False, choices=('True','False'))
args = parser.parse_args()

if type(args.showports) is not NoneType:
#    os.system("python -m serial.tools.list_ports")
    os.system("py -m serial.tools.list_ports")
    exit(0)

if type(args.comport) is NoneType:
    print ("--comport <COMPORT> is required!")
    print ("--showports True   will show available comports")
    exit(1)

print ("Connecting to LEGO DNA Sequencer on Arduino on Port",args.comport)

SerialObj = serial.Serial(args.comport) # COMxx   format on Windows

#SerialObj = serial.Serial('COM4') # COMxx   format on Windows
                                   # ttyUSBx format on Linux

SerialObj.baudrate = 115200  # set Baud rate to 9600
SerialObj.bytesize = 8     # Number of data bits = 8
SerialObj.parity   ='N'    # No parity
SerialObj.stopbits = 1     # Number of Stop bits = 1

root=tk.Tk()
root.title("LEGO DNA Sequencer")
root.geometry("1540x340")
root.attributes('-fullscreen', True)
label = tk.Label(root, text=" LEGO DNA Sequencer -- Remote LCD ", font=("Courier", 48), bg="black", fg="white")
label.pack()

Draw()
Refresher()
root.mainloop()

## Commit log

2023-01-14 Create LEGO DNA Sequencer.fz
    [LEGO DNA Sequencer.fz]
2023-01-18 Additional files
    [LEGO DNA Sequencer - Arduino and LCD.stl, LEGO DNA Sequencer - Buzzer Mount.stl, LEGO DNA Sequencer - Color Sensor and Motor Drive Mount.stl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]
2023-01-18 File updates
    [LEGO DNA Sequencer.fz]
2023-03-10 Update LEGO DNA Sequencer - Stepper Motor Mount.stl
    [LEGO DNA Sequencer - Stepper Motor Mount.stl]
2023-04-17 Fixed Breadboard Schematic 2 missing wires
    - 5V to Motor Driver
    - Gnd to Motor Driver
    [LEGO DNA Sequencer.fz]
2023-04-17 Updated images
    Breadboard and Schematic with 2 added wires
2023-04-17 Update LEGO DNA Sequencer and DIY Construction.pdf
    Fixed missing 2 wires in documentation
2023-04-19 Update LEGO DNA Sequencer.fz
    Added another Gnd wire for LCD
    [LEGO DNA Sequencer.fz]
2023-04-19 LEGO DNA Sequencer - LCD and Rotary Encoder Unit Test
    Updated the output port pin for the LED
2023-04-22 Update LEGO DNA Sequencer - LEGO Tray.stl
    Improvement to gear teeth
    [LEGO DNA Sequencer - LEGO Tray.stl]
2023-04-24 Update LEGO DNA Sequencer - Stepper Motor Mount.stl
    Aligned mounting screws holes.
    [LEGO DNA Sequencer - Stepper Motor Mount.stl]
2023-05-06 Moved Arduino Code
    Code moved to accommodate Arduino IDE naming
2023-07-05 Create LEGO DNA Sequencer - Blocks x 25.stl
    [LEGO DNA Sequencer - Blocks x 25.stl]
2023-07-05 Printable LEGO blocks
    If LEGO blocks are not available, print them in draft mode
    [LEGO Blocks x25.3mf]
2023-08-07 Create LEGO DNA Sequencer Placard.pdf
    8.5 x 11 Placard to print for system demos
2025-04-08 Create LEGO DNA Sequencer Calibration.pdf
2025-08-06 Added Instructions and Better Debug Output
    Instructions:
    -Remove LEGO tray
    -Remove the gear from the top of the stepper motor shaft
    -Insert the 10 LEGO test bricks YYRRBBGGYY into the LEGO tray
    -Manually slide the LEGO tray backwards and forwards under the sensor
    Display color names
2025-08-12 Replaced PySimpleGUI with FreeSimpleGUI
    Version 5+ of PySimpleGUI became unusable so switched to FreeSimpleGUI which has a compatible API.
    [RemoteLCD_PySimpleGUI.py]
2025-08-12 Fixed Refresher loop timing
    [RemoteLCD_tkinter.py]
2025-08-12 STL Updates
    LEGO Tray and Gear Mount Updates
    [LEGO DNA Sequencer - LEGO Tray.stl, LEGO DNA Sequencer - Tray Holder and Gear Mount.stl]
2025-08-18 Replace PySimpleGUI with FreeSimpleGUI
    PySimpleGUI is no longer available and FreeSimpleGUI is functionally equivalent.
    [RemoteLCD_FreeSimpleGUI.py]
2025-08-18 Update LEGO DNA Sequencer and DIY Construction.pdf
    Switched from PySimpleGui to FreeSimpleGUI
